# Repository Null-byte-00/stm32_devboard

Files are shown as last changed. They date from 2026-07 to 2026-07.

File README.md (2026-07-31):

# Custom Designed STM32F401CCU6 Dev Board
This is a 4 layer STM32F401CCU6 Dev Board I designed and sent for fabrication and assembly at JLCPCB<br>
the picture of the board's front and back:<br>
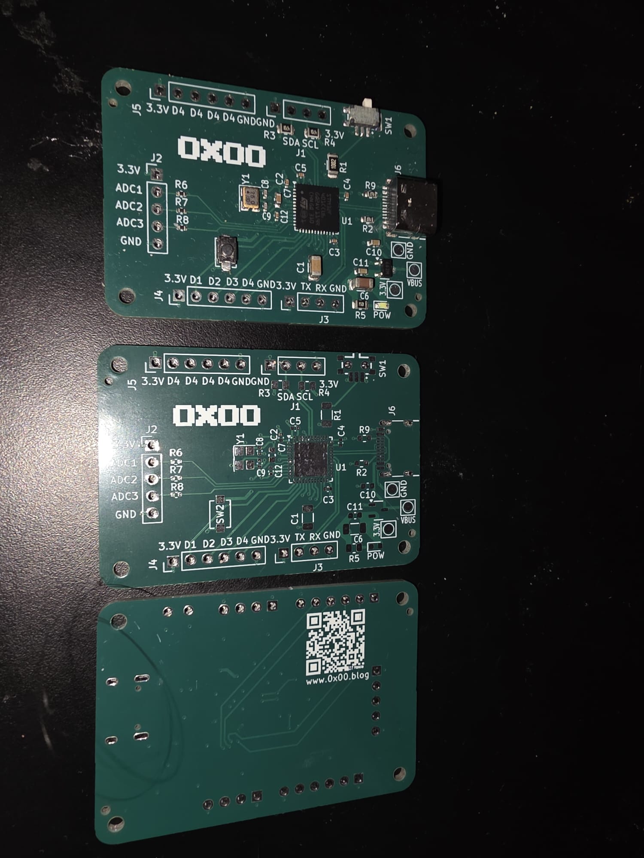
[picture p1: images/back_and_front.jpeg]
<br>
It still has a few problems I mentioned later in this document.
## Schematic and pcb layout
the board was designed with kicad. It has 4 layers including a ground plane, power plane and 2 signal layer.<br>
circuit schematic:<br>
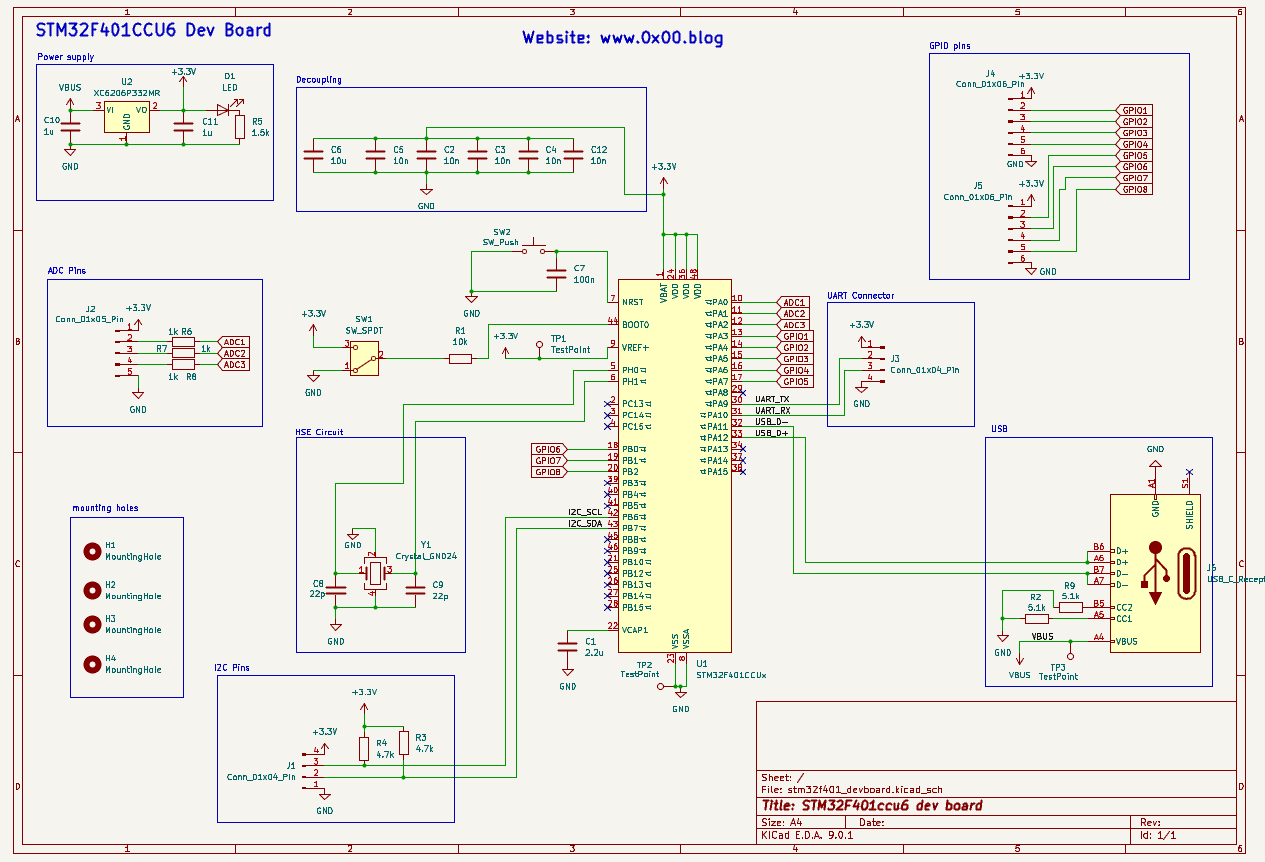
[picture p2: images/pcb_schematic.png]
<br>
a view of pcb layout:<br>
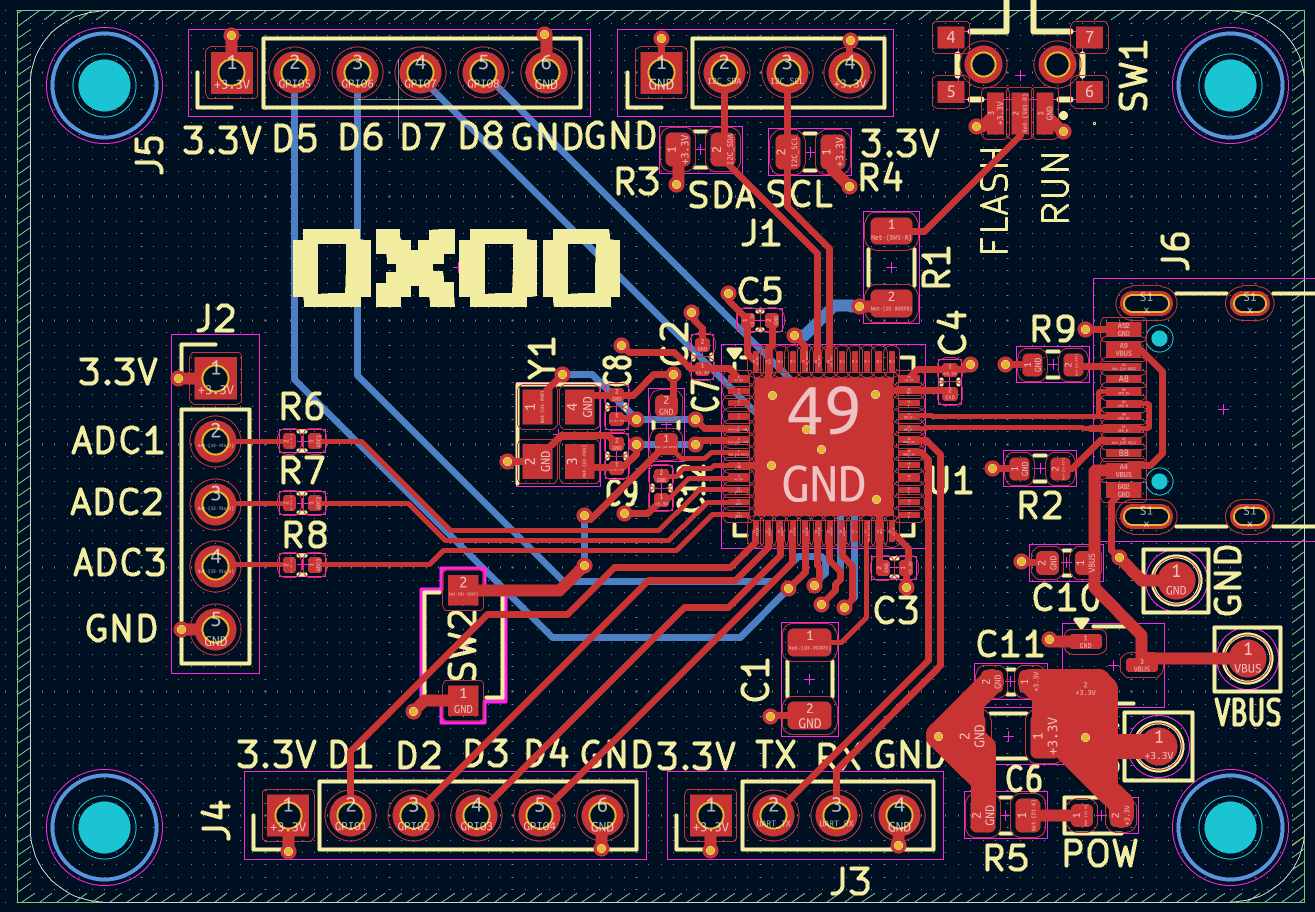
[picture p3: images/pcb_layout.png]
<br>
Kicad 3d viewer:<br>
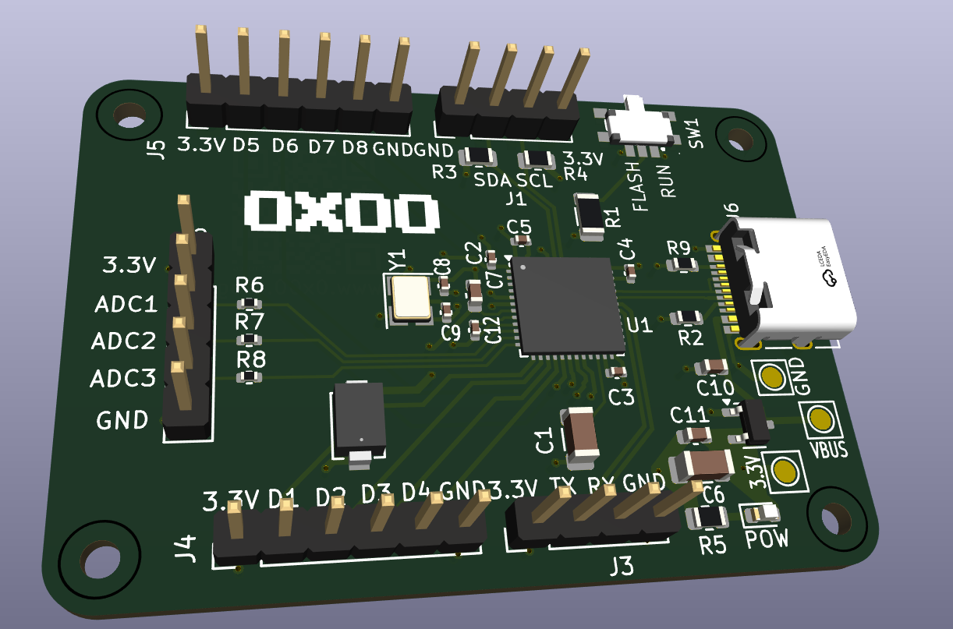
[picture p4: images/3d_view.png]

## Problems with this version
Since the design was rushed and this being my first microcontroller design there are a few problems with this version I'm trying to solve in later iterations.<br><br>
1. Wrong oscillator and USB connection
I chose the wrong oscillator for the board's high speed clock. and since stm32's usb connection requires a clock multiple of 1MHz to establish a USB connection, this board is unable to interact through USB.<br>
And since I didn't add a SWD connector, the only way to program the board is with a UART to USB connector connected to the board's UART pins.<br>
But the board still needs to be powered by USB.<br>
Here's a picture of the board connected to my laptop through a UARD-to-USB module:<br>
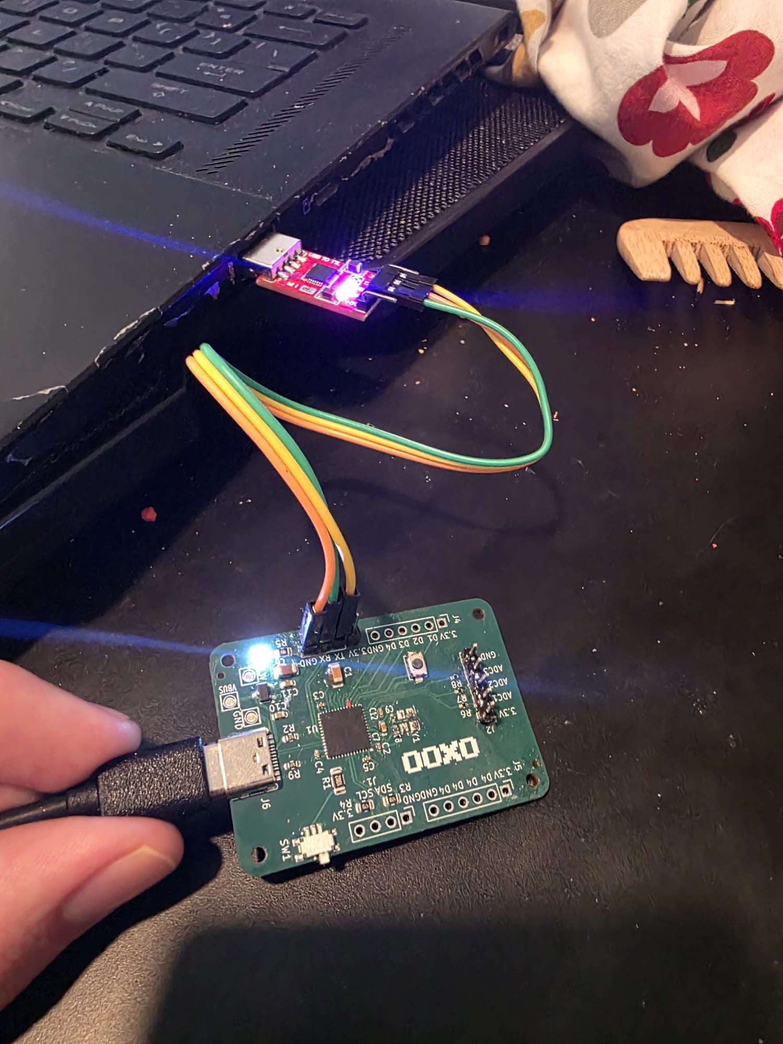
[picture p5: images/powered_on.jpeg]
<br><br>
2. there are a few mistakes on the silkscreen<br><br>
3. the position files are auto generated and I had to adjust them before sending for assembly
## Video
See this youtube video for more information about this project:<br>
https://www.youtube.com/shorts/pBtifo1SFRY

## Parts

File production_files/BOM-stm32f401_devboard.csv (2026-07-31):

Comment | Designator | Footprint | LCSC | Quantity
TestPoint | TP3 | TestPoint_Pad_D1.5mm |  | 1
TestPoint | TP2 | TestPoint_Pad_D1.5mm |  | 1
2.2u | C1 | C_1206_3216Metric | C50254 | 1
SW_Push | SW2 | SW_TS-1088_XNP | C720477 | 1
5.1k | R9 | R_0603_1608Metric | C23186 | 1
USB_C_Receptacle_USB2.0_14P | J6 | USB_C_Receptacle_HRO_TYPE-C-31-M-12 | C165948 | 1
5.1k | R2 | R_0603_1608Metric | C23186 | 1
Conn_01x06_Pin | J5 | PinHeader_1x06_P2.54mm_Vertical |  | 1
Conn_01x06_Pin | J4 | PinHeader_1x06_P2.54mm_Vertical |  | 1
Conn_01x04_Pin | J3 | PinHeader_1x04_P2.54mm_Vertical |  | 1
Conn_01x05_Pin | J2 | PinHeader_1x05_P2.54mm_Vertical |  | 1
Conn_01x04_Pin | J1 | PinHeader_1x04_P2.54mm_Vertical |  | 1
10n | C3 | C_0402_1005Metric | C1524 | 1
SW_SPDT | SW1 | K3-1296S-E2_HRO | C145852 | 1
Crystal_GND24 | Y1 | Crystal_SMD_3225-4Pin_3.2x2.5mm | C160454 | 1
XC6206P332MR | U2 | SOT-23-3 | C5446 | 1
1k | R8 | R_0402_1005Metric | C11702 | 1
1k | R6 | R_0402_1005Metric | C11702 | 1
1.5k | R5 | R_0805_2012Metric | C4310 | 1
4.7k | R4 | R_0805_2012Metric | C17673 | 1
4.7k | R3 | R_0805_2012Metric | C17673 | 1
10k | R1 | R_1206_3216Metric | C17902 | 1
LED | D1 | LED_0603_1608Metric | C2290 | 1
10n | C12 | C_0402_1005Metric | C1524 | 1
1u | C11 | C_0603_1608Metric | C15849 | 1
1u | C10 | C_0603_1608Metric | C15849 | 1
22p | C9 | C_0402_1005Metric | C1555 | 1
22p | C8 | C_0402_1005Metric | C1555 | 1
100n | C7 | C_0603_1608Metric | C14663 | 1
10u | C6 | C_1206_3216Metric | C13585 | 1
10n | C5 | C_0402_1005Metric | C1524 | 1
10n | C4 | C_0402_1005Metric | C1524 | 1
10n | C2 | C_0402_1005Metric | C1524 | 1
STM32F401CCUx | U1 | QFN-48-1EP_7x7mm_P0.5mm_EP5.6x5.6mm | C79861 | 1
TestPoint | TP1 | TestPoint_Pad_D1.5mm |  | 1
1k | R7 | R_0402_1005Metric | C11702 | 1

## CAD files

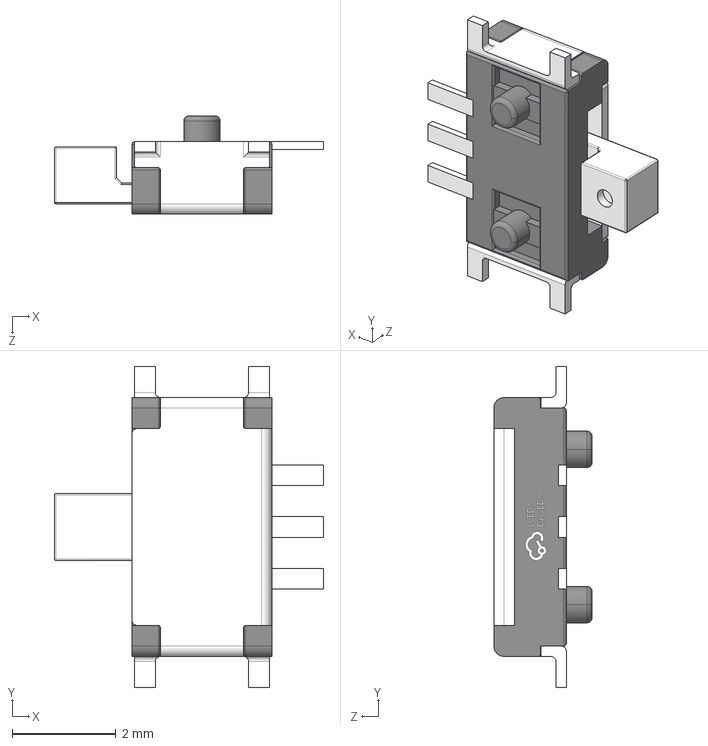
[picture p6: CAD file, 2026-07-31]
footprint_3d_models/SPDT_Switch/3d_model/SW-TH_K3-1293S-E2.step
5.20 x 6.20 x 1.90 mm
翋极
褲极

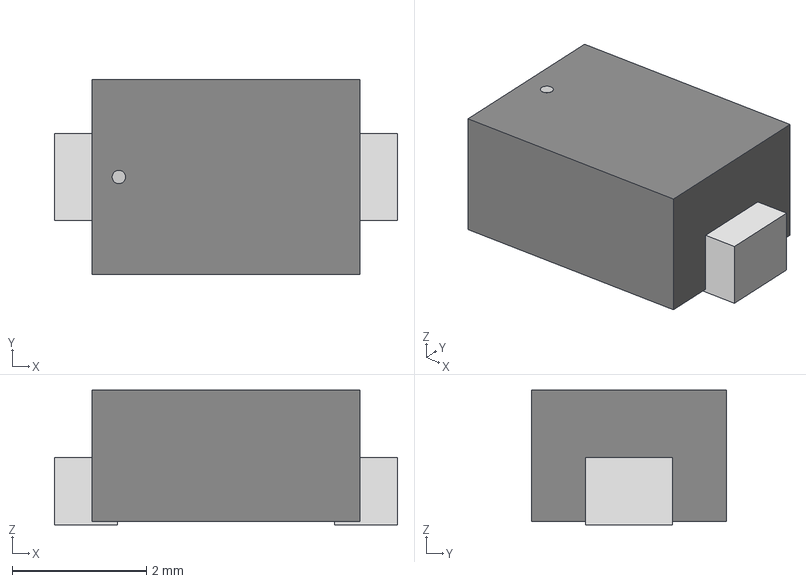
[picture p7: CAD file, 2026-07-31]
footprint_3d_models/SPST_Switch/3d_models/SW_TS-1088_XNP.step
5.11 x 2.90 x 2.01 mm

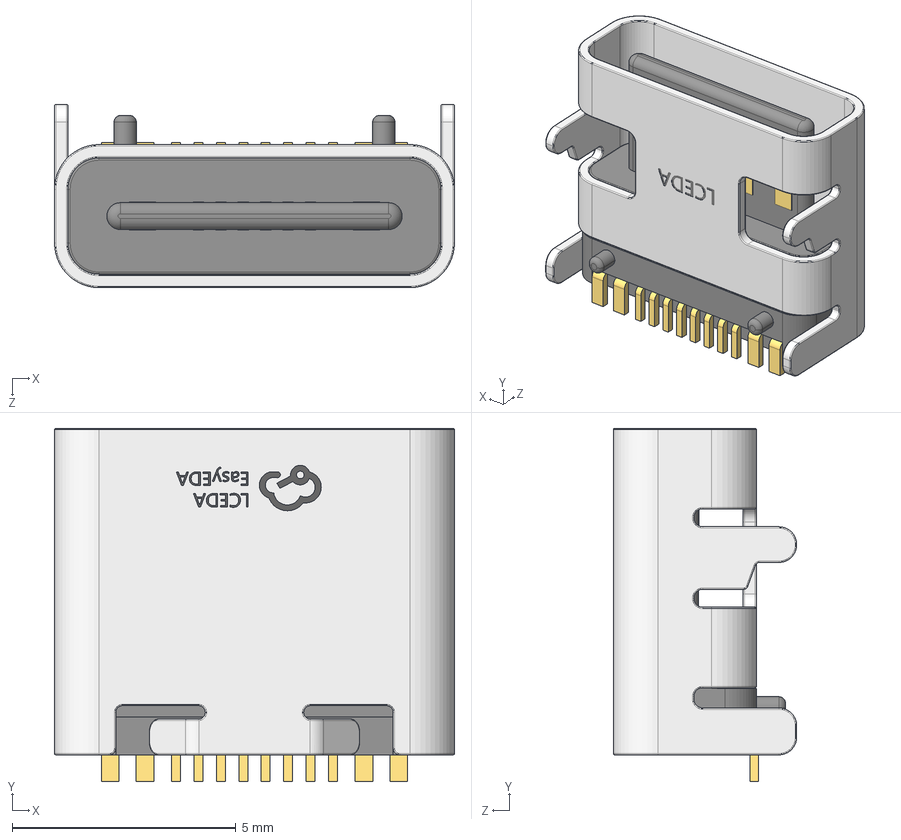
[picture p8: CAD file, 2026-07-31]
footprint_3d_models/USB_C_Connector/3d_model/USB-C_SMD-TYPE-C-31-M-12_1.step
8.94 x 7.90 x 4.10 mm

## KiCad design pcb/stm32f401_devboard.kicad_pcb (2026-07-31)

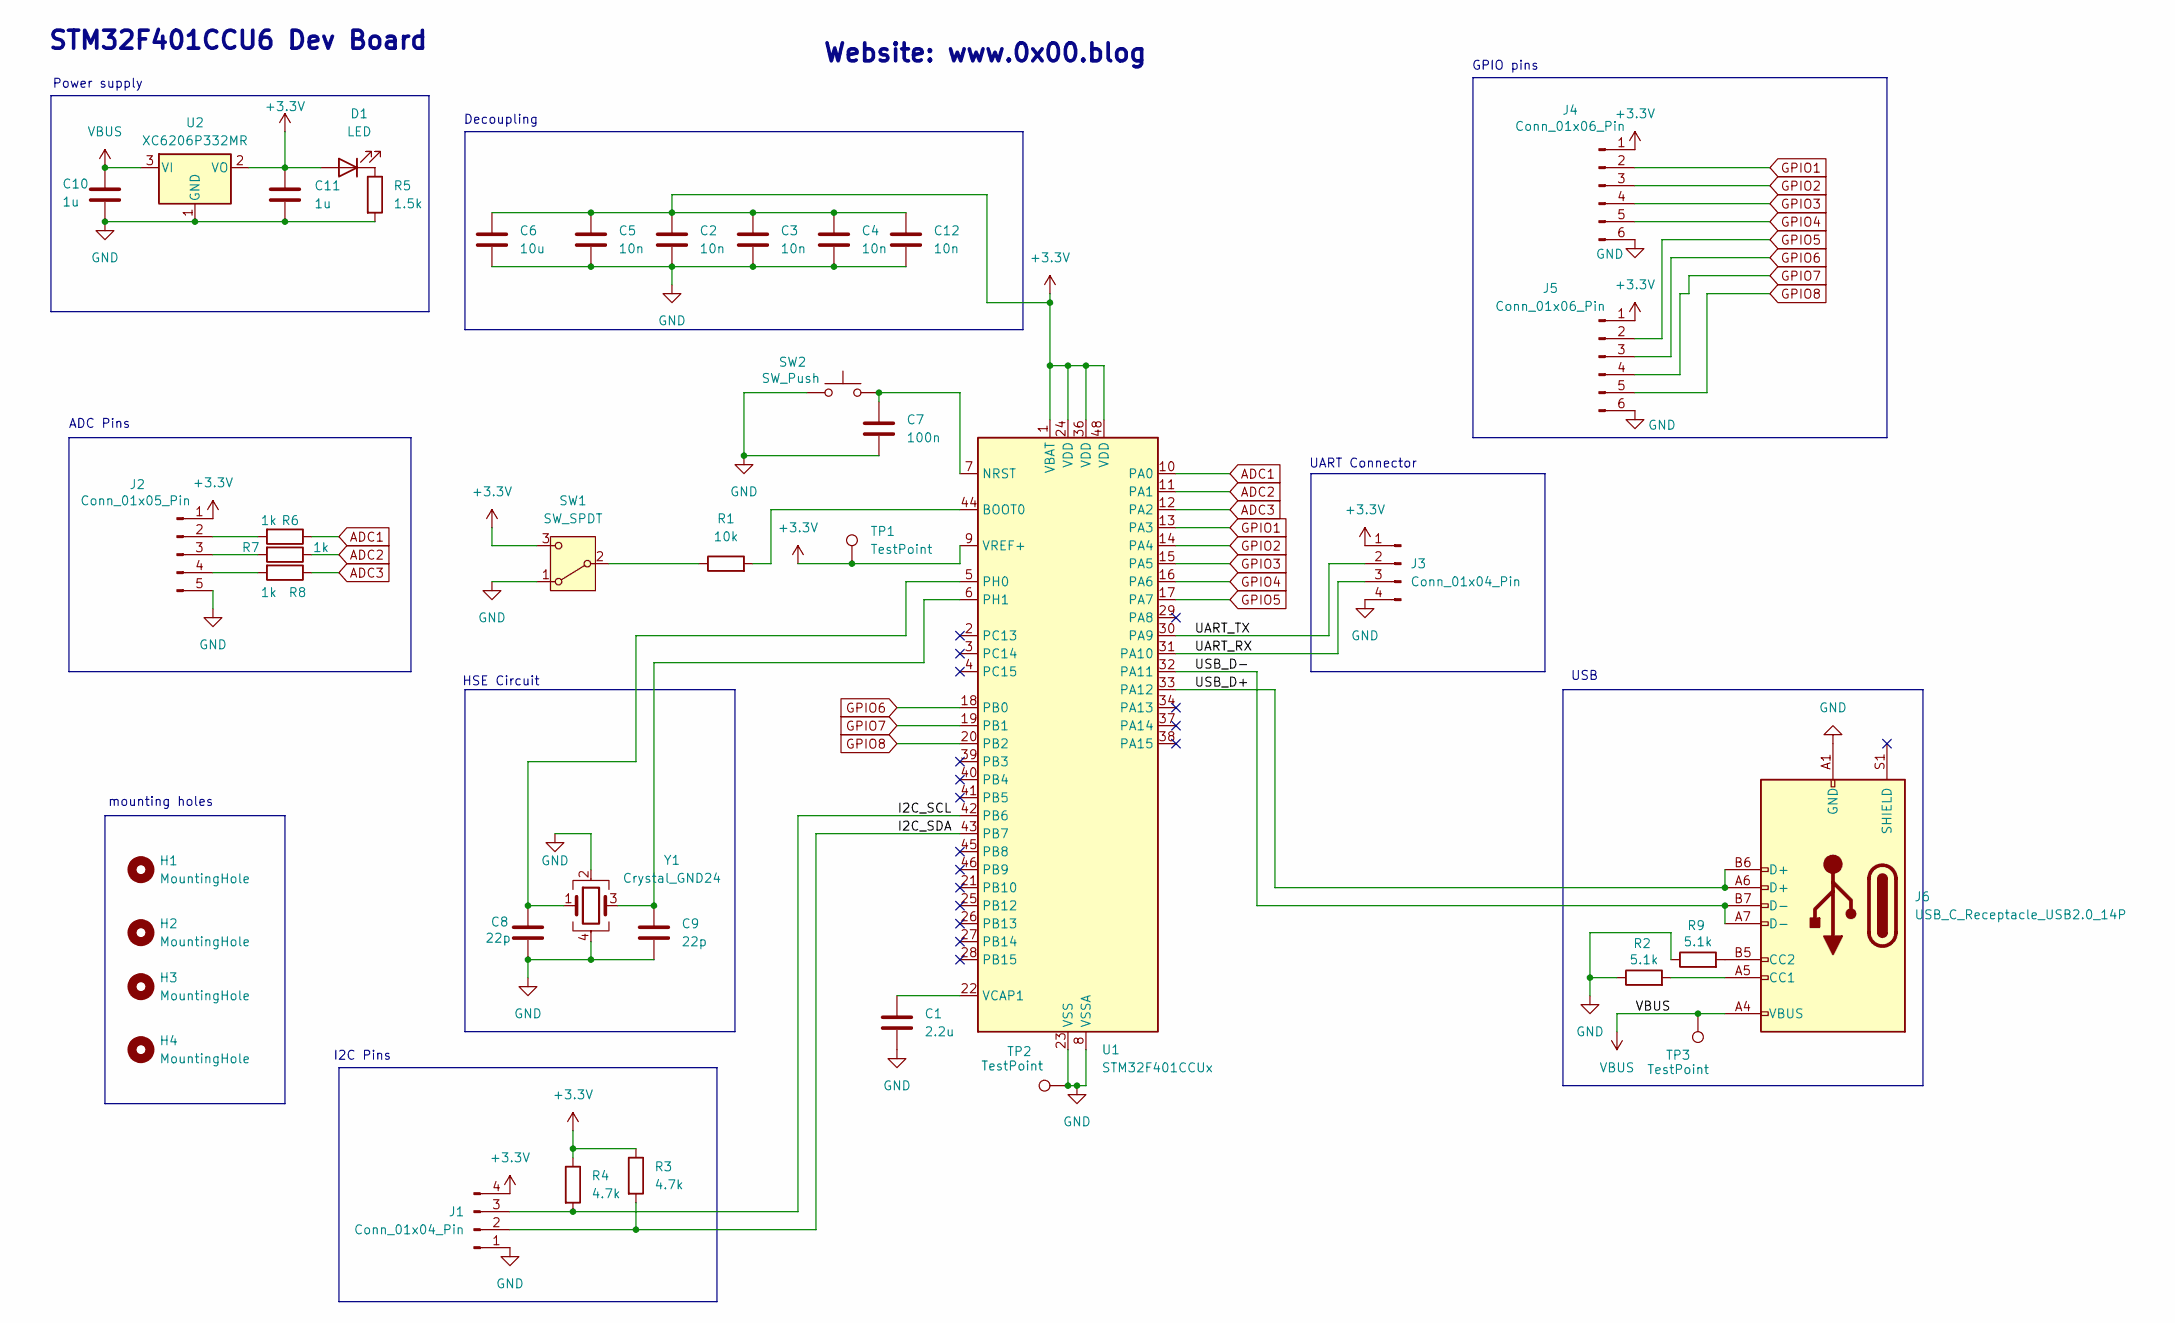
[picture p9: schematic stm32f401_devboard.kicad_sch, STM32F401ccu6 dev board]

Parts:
C1: 2.2u; C_1206_3216Metric
C2, C3, C4, C5, C12: 10n; C_0402_1005Metric
C6: 10u; C_1206_3216Metric
C7: 100n; C_0603_1608Metric
C8, C9: 22p; C_0402_1005Metric
C10, C11: 1u; C_0603_1608Metric
D1: LED; LED_0603_1608Metric
H1, H2, H3, H4: MountingHole; MountingHole_2.1mm
J1, J3: Conn_01x04_Pin; PinHeader_1x04_P2.54mm_Vertical
J2: Conn_01x05_Pin; PinHeader_1x05_P2.54mm_Vertical
J4, J5: Conn_01x06_Pin; PinHeader_1x06_P2.54mm_Vertical
J6: USB_C_Receptacle_USB2.0_14P; USB_C_Receptacle_HRO_TYPE-C-31-M-12
R1: 10k; R_1206_3216Metric
R2, R9: 5.1k; R_0603_1608Metric
R3, R4: 4.7k; R_0805_2012Metric
R5: 1.5k; R_0805_2012Metric
R6, R7, R8: 1k; R_0402_1005Metric
SW1: SW_SPDT; SW-TH_K3-1293S-E2
SW2: SW_Push; SW_TS-1088_XNP
TP1, TP2, TP3: TestPoint; TestPoint_Pad_D1.5mm
U1: STM32F401CCUx; QFN-48-1EP_7x7mm_P0.5mm_EP5.6x5.6mm
U2: XC6206P332MR; SOT-23-3
Y1: Crystal_GND24; Crystal_SMD_3225-4Pin_3.2x2.5mm

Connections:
+3.3V: C2.1, C3.1, C4.1, C5.1, C6.1, C11.1, C12.1, D1.2 (A), J1.4, J2.1, J3.1, J4.1, J5.1, R3.1, R4.1, SW1.3 (C), TP1.1, U1.1 (VBAT), U1.9 (VREF+), U1.24 (VDD), U1.36 (VDD), U1.48 (VDD), U2.2 (VO)
/I2C_SCL: J1.3, R4.2, U1.42 (PB6)
/I2C_SDA: J1.2, R3.2, U1.43 (PB7)
/UART_RX: J3.3, U1.31 (PA10)
/UART_TX: J3.2, U1.30 (PA9)
/USB_D+: J6.A6 (D+), J6.B6 (D+), U1.33 (PA12)
/USB_D-: J6.A7 (D-), J6.B7 (D-), U1.32 (PA11)
ADC1: R6.1, U1.10 (PA0)
ADC2: R7.1, U1.11 (PA1)
ADC3: R8.1, U1.12 (PA2)
GND: C1.2, C2.2, C3.2, C4.2, C5.2, C6.2, C7.2, C8.2, C9.2, C10.2, C11.2, C12.2, J1.1, J2.5, J3.4, J4.6, J5.6, J6.A1 (GND), J6.A12 (GND), J6.B1 (GND), J6.B12 (GND), R2.1, R5.2, R9.1, SW1.1 (A), SW2.1, TP2.1, U1.8 (VSSA), U1.23 (VSS), U1.35 (VSS), U1.47 (VSS), U1.49 (VSS), U2.1 (GND), Y1.2, Y1.4
GPIO1: J4.2, U1.13 (PA3)
GPIO2: J4.3, U1.14 (PA4)
GPIO3: J4.4, U1.15 (PA5)
GPIO4: J4.5, U1.16 (PA6)
GPIO5: J5.2, U1.17 (PA7)
GPIO6: J5.3, U1.18 (PB0)
GPIO7: J5.4, U1.19 (PB1)
GPIO8: J5.5, U1.20 (PB2)
unnamed: D1.1 (K), R5.1
unnamed: J2.2, R6.2
unnamed: J2.3, R7.2
unnamed: J2.4, R8.2
unnamed: J6.A5 (CC1), R2.2
unnamed: J6.B5 (CC2), R9.2
unnamed: R1.1, SW1.2 (B)
unnamed: R1.2, U1.44 (BOOT0)
unnamed: C7.1, SW2.2, U1.7 (NRST)
unnamed: C8.1, U1.5 (PH0), Y1.1
unnamed: C9.1, U1.6 (PH1), Y1.3
unnamed: C1.1, U1.22 (VCAP1)
VBUS: C10.1, J6.A4 (VBUS), J6.A9 (VBUS), J6.B4 (VBUS), J6.B9 (VBUS), TP3.1, U2.3 (VI)

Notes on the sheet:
Decoupling
USB
HSE Circuit
STM32F401CCU6 Dev Board
UART Connector
I2C Pins
mounting holes
Power supply
Website: www.0x00.blog
GPIO pins
ADC Pins

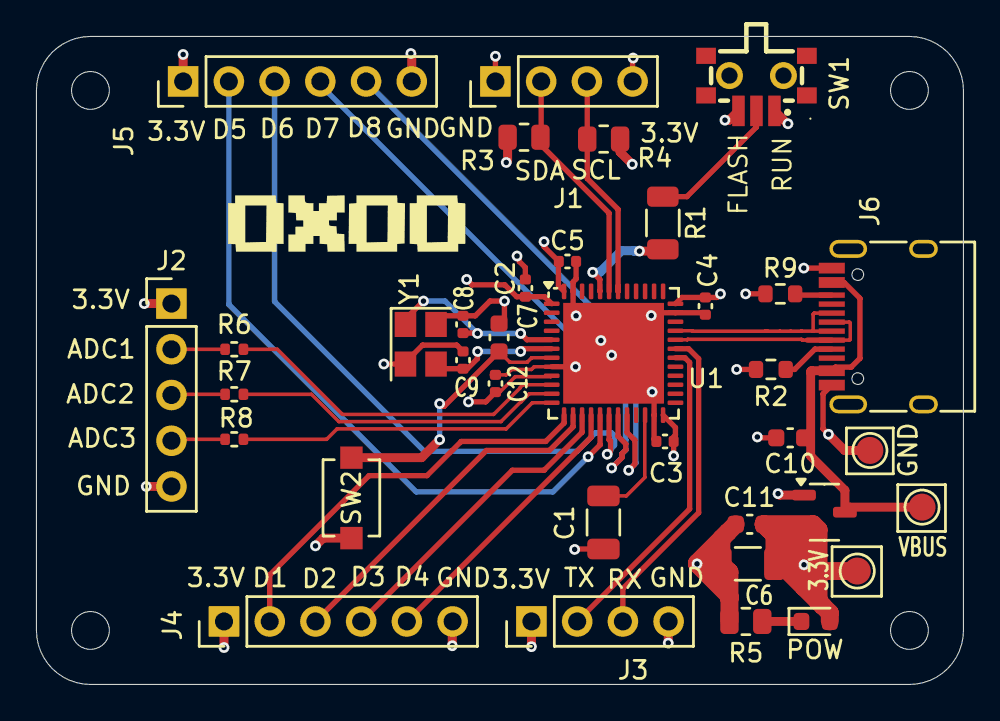
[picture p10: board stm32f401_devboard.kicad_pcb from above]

Board: 4 copper layers, 51.5 x 36.0 mm, 40 parts (0 on the bottom side), 32 nets.
